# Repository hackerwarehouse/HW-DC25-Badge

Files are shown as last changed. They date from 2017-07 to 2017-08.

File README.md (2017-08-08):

# HW-DC25-Badge

This is the project page for the Hacker Warehouse electronic badge that was made for DEF CON 25.

## Background / timeline of badge development

* This was our first attempt at custom hardware / any electronics project at a larger scale
* 2 hardware revisions, 1 silkscreen revision = 3 prototype runs = 4-5 months
* After final board design was obtained, coding started (all code prior was test code to ensure components were working)
* 2 week code sprint before code needed to be frozen for mass badge flashing
* All boards flashed / all components obtained the week of travel of Las Vegas (one final box arrived the day prior to leaving which gave me some anxiety as well)
* 425 badges were produced 

## Badge Specs

* 96×64 Graphic Full Color OLED Display
* 14x Mini NeoPixel RGB LEDs
* ESP8266EX
* 4 tactile buttons arranged in Joypad configuration
* 8 MB Storage
* Powered via 2 AA batteries

## Badge Functions:

* 802.11 channel activity monitor
* Access point scanner
* LED patterns
* OLED animations
* Personalization
* Other useful network tools

## Release Notes
* There was debate if any/all the mischief tools should be included in the badge by default, include it but have them keycode unlockable, or just not include it in stock firmware. Because we know the people working on/in the Black Hat and DEF CON network, along with wanting to have a usable network without causing more issues, the features were not included. 
  * The continued usage of the word 'locked' in all areas made people assume it was all unlockable during the con. We should have chosen different words for the various areas of inclusion. Sorry about that. 

* Multiple reports during DEF CON on wifi functions not working after x usage. Originally suspected it was the sleep/wakeup or disconnect functions not being triggered properly but that doesn't seem to be it. 
  * As previously mentioned, all the badge software was in a two week sprint which didn't leave much or any time for debugging 

* We originally stated source/binaries would be released after the con but because of wifi bug we were wanting to debug and fix it prior to first public release. It seems like people want the code first so we are releasing it as is with the hopes more eyes on it the better and fixes can be submitted. 

## Compiling

These instructions will get you a copy of the project up and running on your local machine.

### Prerequisites

What things you need to install the software and how to install them

```
1. Arduino / compiler
2. Libraries via package manager
  https://github.com/esp8266/Arduino -> http://arduino.esp8266.com/versions/2.3.0/package_esp8266com_index.json
  https://github.com/adafruit/Adafruit_NeoPixel
  https://github.com/kitesurfer1404/WS2812FX
3. Manually copy the two other library packages to Arduino libraries folder
4. 3.3v serial cable
5. and of course a Hacker Warehouse DC25 Badge
```

### Uploading firmware to badge

1. Press / hold the up button on badge
2. Connect 3.3v serial cable
3. Use arduino compile to upload or use other methods such as esptool or esp8266_flasher (with binary file)
  * 115200

## Authors / Contributors

* **Garrett Gee**
* **Jaycon Systems**

## Acknowledgments

* Hat tip to anyone who's code was used
* All the supporters of this project
*

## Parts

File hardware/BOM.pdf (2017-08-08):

Part | Quantity | Manufacturer Part Number
0.1uF Capacitor | 14 | CL05B104KO5NNNC
10uF Capacitor | 2 | CL10A106MA8NRNC
0.1uF Capacitor | 3 | CL10B104KA8NNNC
10uF Capacitor | 2 | GRM188R61A106KE69D
10pF Capacitor | 2 | C1608C0G1H100C080AA
5.6pF Capacitor | 1 | CL10C5R6DB8NNNC
Schottky Diode | 1 | SS1P3L-M3/84A
RGB LED | 14 | 2659
Slide Switch | 1 | AYZ0202AGRLC
Push Button | 4 | TL3301NF100QG
Battery Holder | 1 | BC2AAPC
ESP8266 | 1 | ESP8266EX
LED Driver Regulator | 1 | FAN5331SX
8Mbit Flash | 1 | AT25SF081-SSHD-T
10uH Inductor | 1 | SRU5018-100Y
96x64 OLED | 1 | UG-9664HDDAG01
PCB | 1
100K Resistor | 1 | RC0603JR-07100KL
33K Resistor | 1 | RC0603FR-0733KL
10K Resistor | 5 | RC0603JR-0710KL
1M Resistor | 1 | RC0603FR-071ML
200 Resistor | 1 | RC0603FR-07200RL
16.5K Resistor | 1 | RC0603FR-0716K5L
12K Resistor | 1 | RC0603FR-0712KL
Stencil | 1
26MHz Crystal | 1 | TSX-3225 26.0000MF09Z-AC0

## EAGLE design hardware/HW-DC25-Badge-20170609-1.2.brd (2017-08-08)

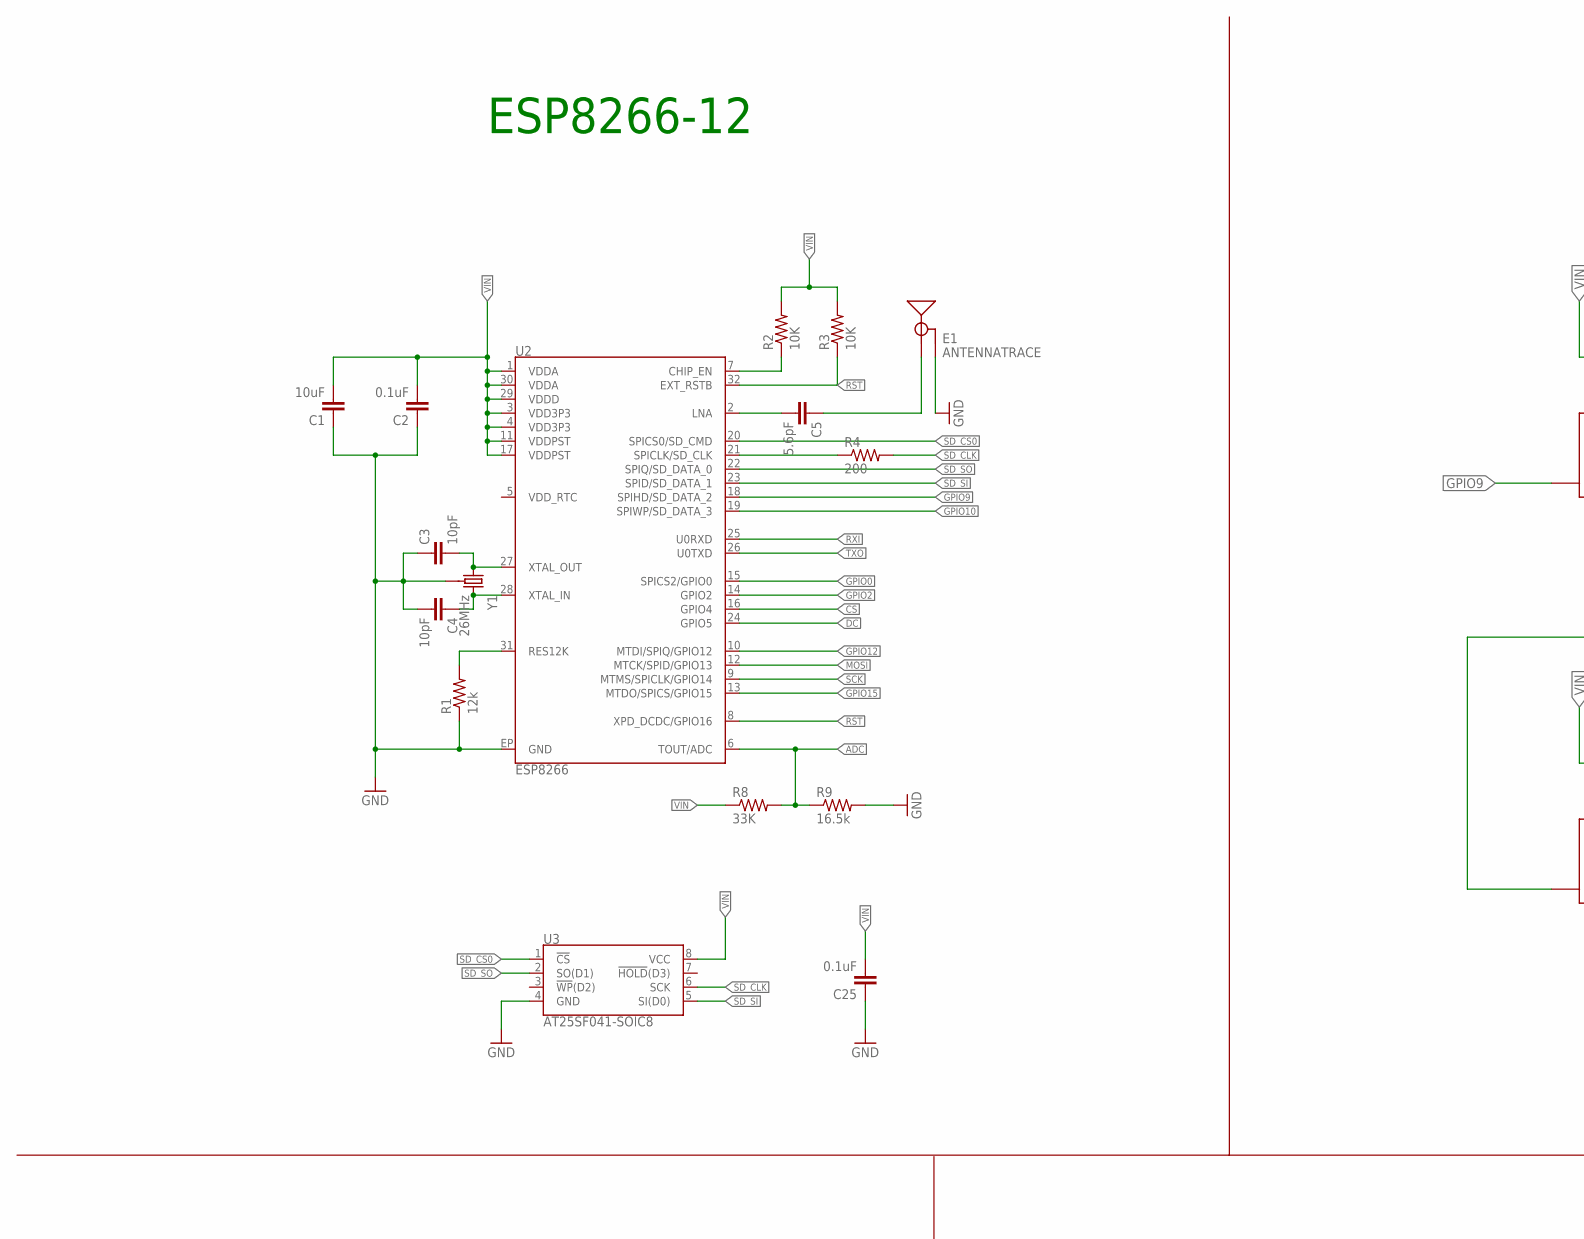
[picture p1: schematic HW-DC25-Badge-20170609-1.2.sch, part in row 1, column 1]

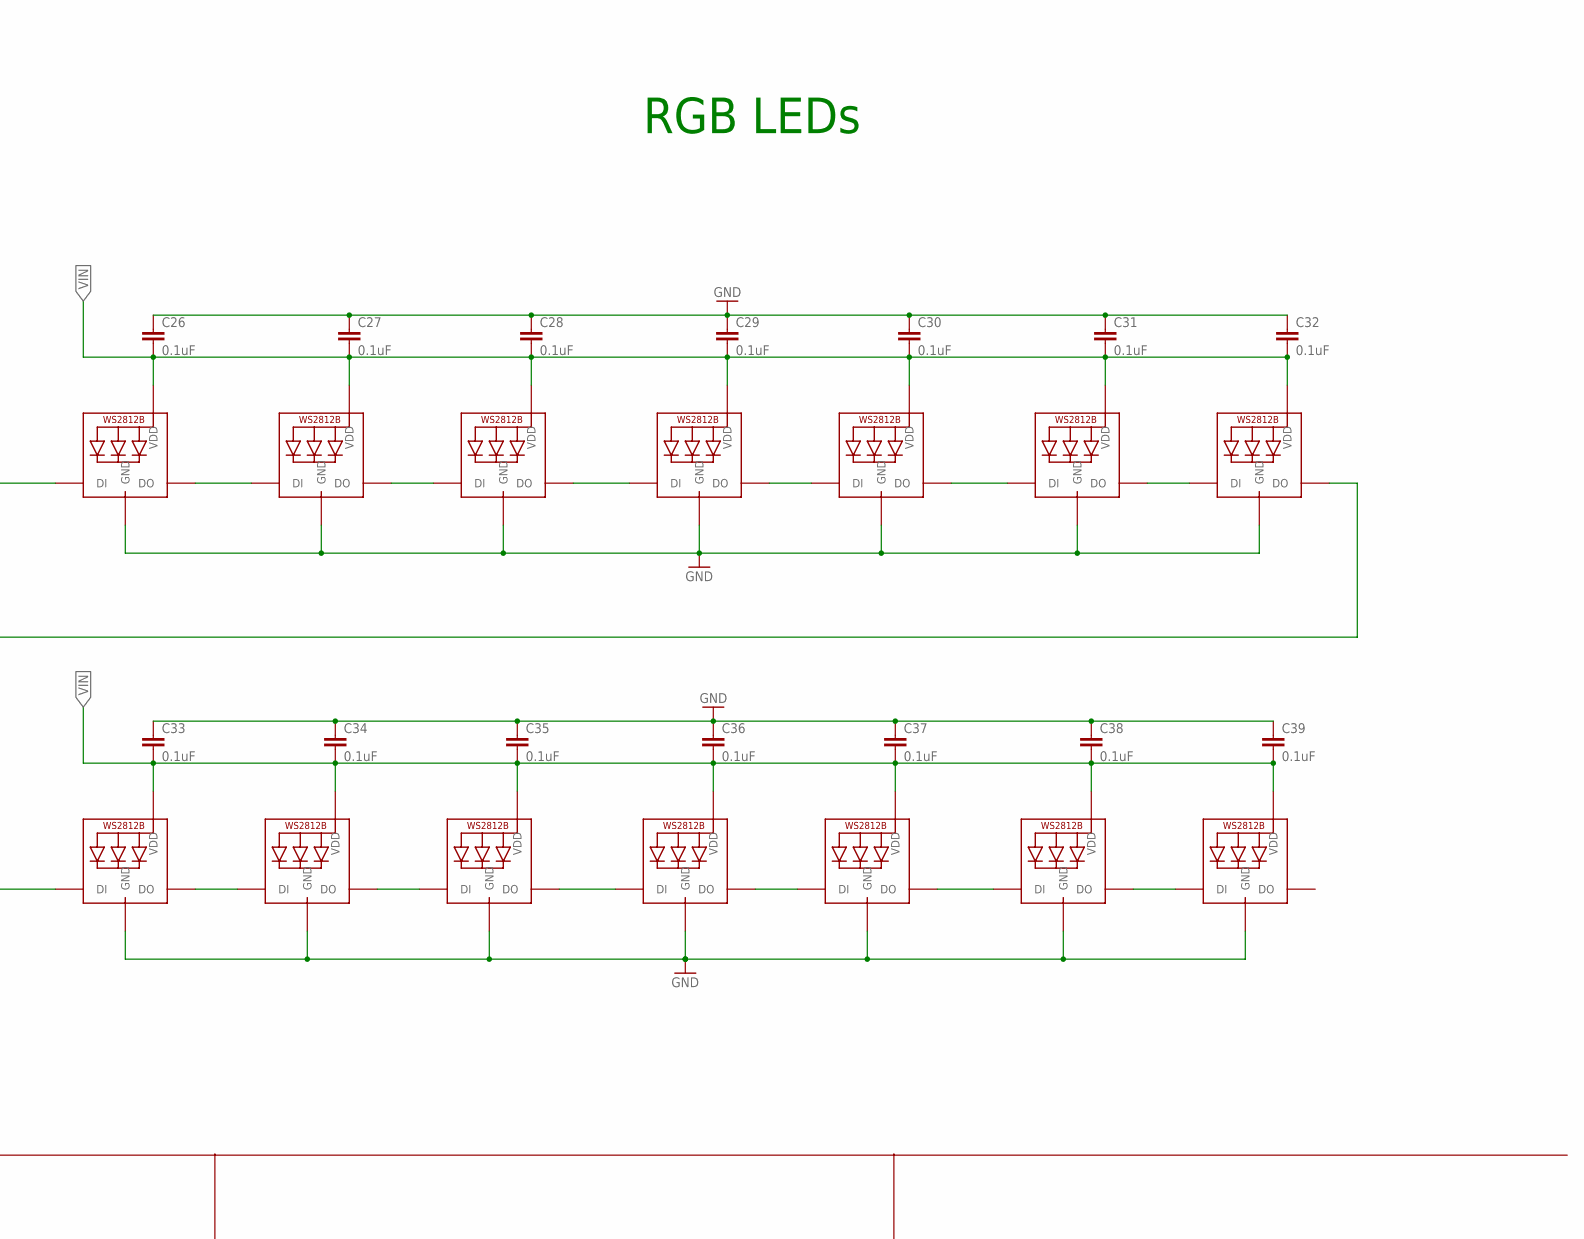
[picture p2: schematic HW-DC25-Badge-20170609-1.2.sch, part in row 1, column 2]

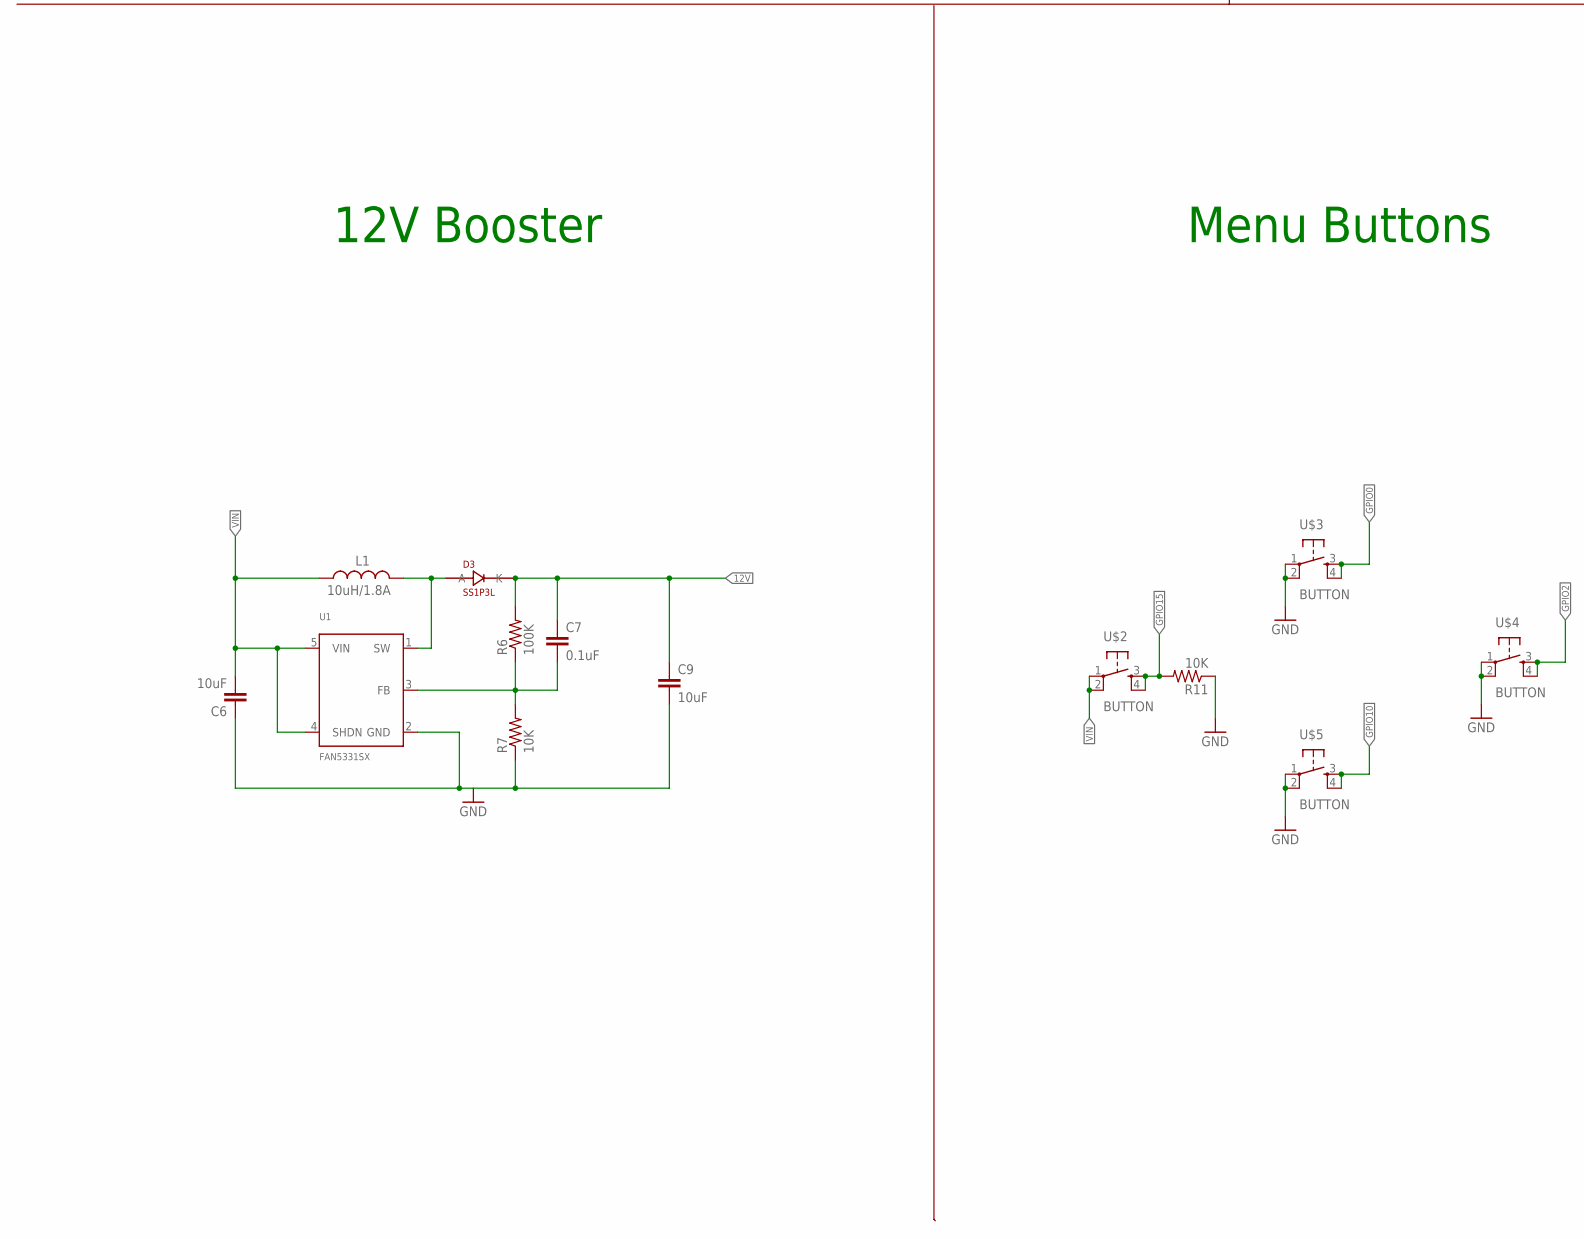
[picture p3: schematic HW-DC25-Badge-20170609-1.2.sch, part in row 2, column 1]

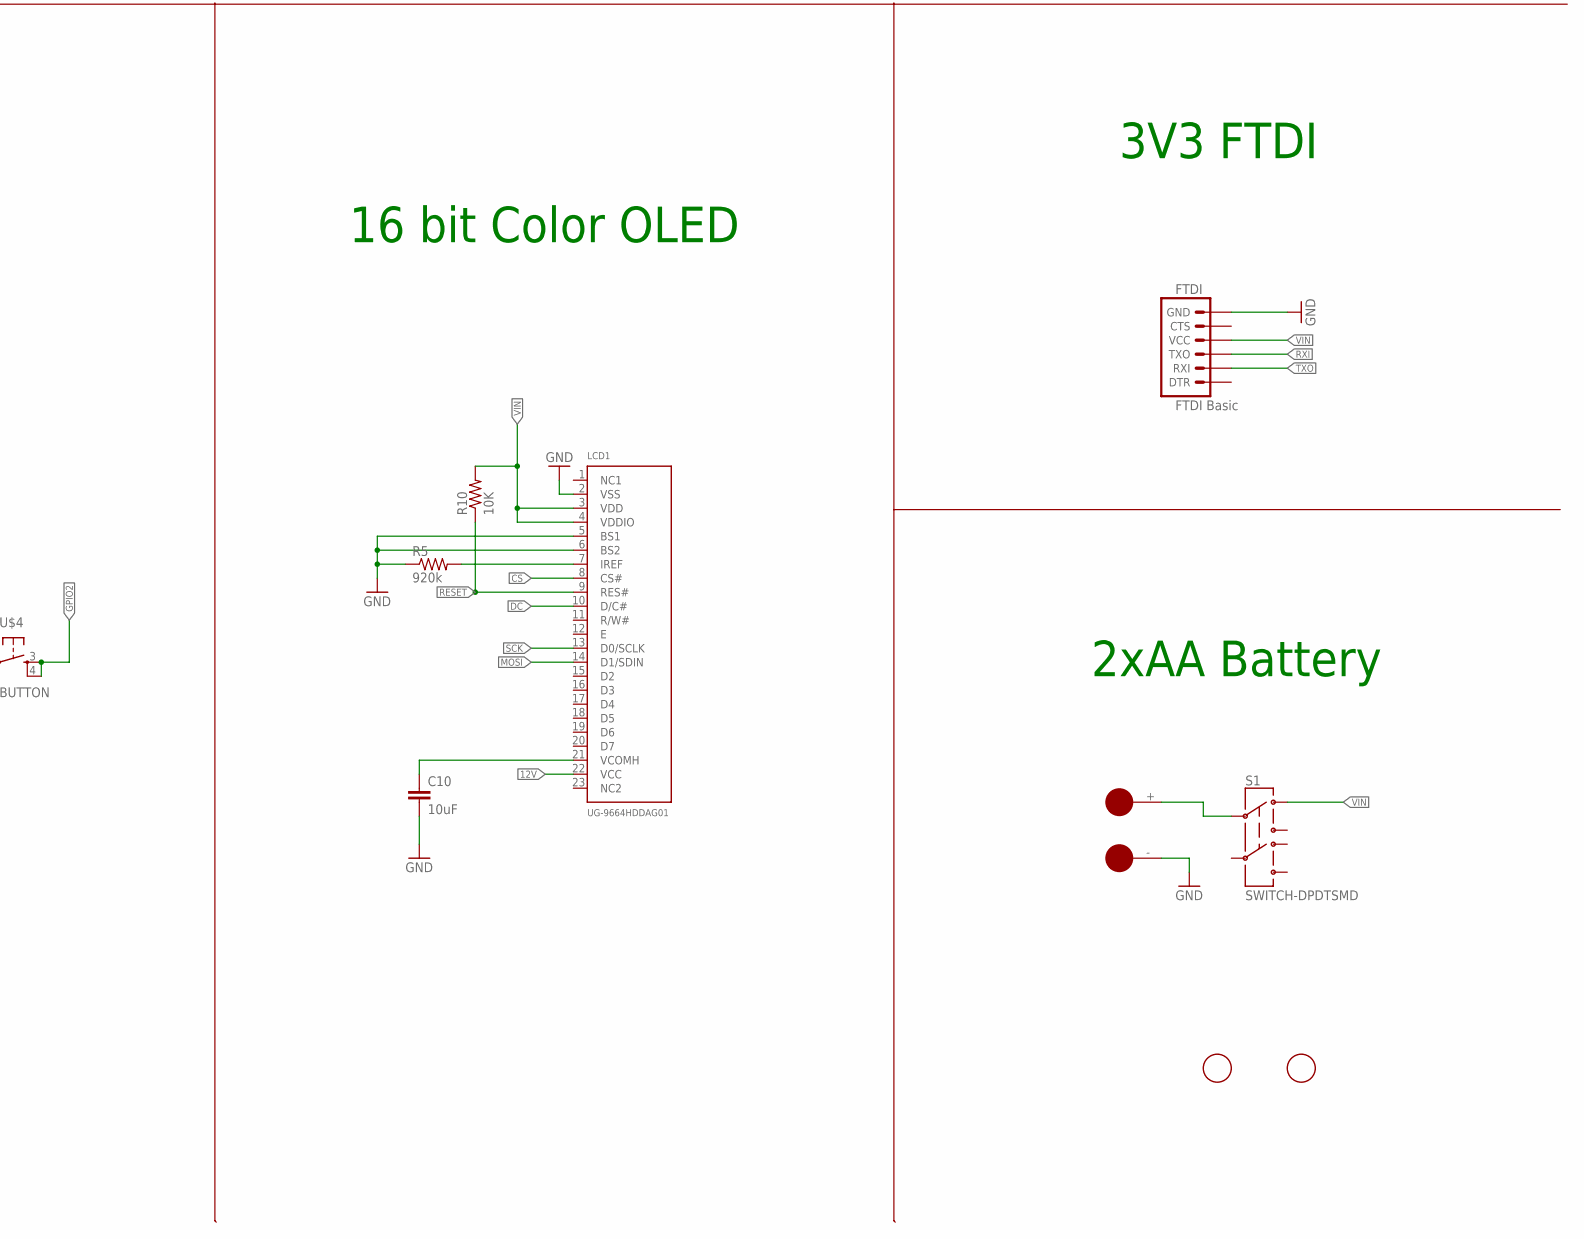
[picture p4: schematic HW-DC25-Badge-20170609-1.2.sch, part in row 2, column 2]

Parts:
C1, C6, C9, C10: 10uF; CAP0603
C2, C7, C25: 0.1uF; CAP0603
C3, C4: 10pF; CAP0603
C5: 5.6pF; CAP0603
C26, C27, C28, C29, C30, C31, C32, C33, C34, C35, C36, C37, C38, C39: 0.1uF; CAP0402
D3: SS1P3L; DO220AAL
E1: ANTENNATRACE; TRACE_ANTENNA_2.4GHZ_25.7MM
FTDI: FTDI Basic; 1X06
L1: 10uH/1.8A; SRU5028
LCD1: UG-9664HDDAG01; UG-9664HDDAG01_WRAPAROUND
LED1, LED2, LED3, LED4, LED5, LED6, LED7, LED8, LED9, LED10, LED11, LED12, LED13, LED14: WS2812B3535; LED3535
R1: 12k; RES-0603
R2, R3, R7, R10, R11: 10K; RES-0603
R4: 200; RES-0603
R5: 920k; RES-0603
R6: 100K; RES-0603
R8: 33K; RES-0603
R9: 16.5k; RES-0603
S1: SWITCH-DPDTSMD; AYZ0202
U1: FAN5331SX; SOT23-5
U2: ESP8266; QFN32
U3: AT25SF041-SOIC8; SO08
U$1: BAT_HOLD; AA
U$2, U$3, U$4, U$5: BUTTON
U$6, U$7: FIDUCIAL; FIDUCIAL_1MM
Y1: 26MHz; CRYSTAL-SMD-3.2X2.5

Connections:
12V: C7.1, C9.1, D3.P$1 (K), LCD1.22 (VCC), R6.2
ADC: R8.2, R9.1, U2.6 (TOUT/ADC)
CS: LCD1.8 (CS#), U2.16 (GPIO4)
DC: LCD1.10 (D/C#), U2.24 (GPIO5)
GND: C1.1, C2.1, C3.1, C4.2, C6.1, C9.2, C10.2, C25.1, C26.P$1 (1), C27.P$1 (1), C28.P$1 (1), C29.P$1 (1), C30.P$1 (1), C31.P$1 (1), C32.P$1 (1), C33.P$1 (1), C34.P$1 (1), C35.P$1 (1), C36.P$1 (1), C37.P$1 (1), C38.P$1 (1), C39.P$1 (1), E1.GND, E1.GND2 (GND), FTDI.6 (GND), LCD1.2 (VSS), LCD1.5 (BS1), LCD1.6 (BS2), LED1.4 (GND), LED2.4 (GND), LED3.4 (GND), LED4.4 (GND), LED5.4 (GND), LED6.4 (GND), LED7.4 (GND), LED8.4 (GND), LED9.4 (GND), LED10.4 (GND), LED11.4 (GND), LED12.4 (GND), LED13.4 (GND), LED14.4 (GND), R1.1, R5.1, R7.1, R9.2, R11.1, U1.2 (GND), U2.EP (GND), U3.4 (GND), U$1.-, U$3.1, U$3.2, U$4.1, U$4.2, U$5.1, U$5.2, Y1.2 (GND), Y1.4 (GND)
GPIO0: U2.15 (SPICS2/GPIO0), U$3.3, U$3.4
GPIO2: U2.14 (GPIO2), U$4.3, U$4.4
GPIO9: LED1.1 (DI), U2.18 (SPIHD/SD_DATA_2)
GPIO10: U2.19 (SPIWP/SD_DATA_3), U$5.3, U$5.4
GPIO12: U2.10 (MTDI/SPIQ/GPIO12)
GPIO15: R11.2, U2.13 (MTDO/SPICS/GPIO15), U$2.3, U$2.4
MOSI: LCD1.14 (D1/SDIN), U2.12 (MTCK/SPID/GPIO13)
unnamed: C3.2, U2.27 (XTAL_OUT), Y1.1
unnamed: C4.1, U2.28 (XTAL_IN), Y1.3 (2)
unnamed: C5.2, U2.2 (LNA)
unnamed: C5.1, E1.ANT (SIGNAL)
unnamed: R1.2, U2.31 (RES12K)
unnamed: R2.1, U2.7 (CHIP_EN)
unnamed: D3.P$2 (A), L1.2, U1.1 (SW)
unnamed: R4.1, U2.21 (SPICLK/SD_CLK)
unnamed: LCD1.7 (IREF), R5.2
unnamed: S1.2, U$1.+
unnamed: C7.2, R6.1, R7.2, U1.3 (FB)
unnamed: C10.1, LCD1.21 (VCOMH)
unnamed: LED1.3 (DO), LED2.1 (DI)
unnamed: LED2.3 (DO), LED3.1 (DI)
unnamed: LED3.3 (DO), LED4.1 (DI)
unnamed: LED4.3 (DO), LED5.1 (DI)
unnamed: LED5.3 (DO), LED6.1 (DI)
unnamed: LED6.3 (DO), LED7.1 (DI)
unnamed: LED7.3 (DO), LED8.1 (DI)
unnamed: LED8.3 (DO), LED9.1 (DI)
unnamed: LED9.3 (DO), LED10.1 (DI)
unnamed: LED10.3 (DO), LED11.1 (DI)
unnamed: LED11.3 (DO), LED12.1 (DI)
unnamed: LED12.3 (DO), LED13.1 (DI)
unnamed: LED13.3 (DO), LED14.1 (DI)
RESET: LCD1.9 (RES#), R10.1
RST: R3.1, U2.8 (XPD_DCDC/GPIO16), U2.32 (EXT_RSTB)
RXI: FTDI.3 (TXO), U2.25 (U0RXD)
SCK: LCD1.13 (D0/SCLK), U2.9 (MTMS/SPICLK/GPIO14)
SD_CLK: R4.2, U3.6 (SCK)
SD_CS0: U2.20 (SPICS0/SD_CMD), U3.1 (!CS!)
SD_SI: U2.23 (SPID/SD_DATA_1), U3.5 (SI(D0))
SD_SO: U2.22 (SPIQ/SD_DATA_0), U3.2 (SO(D1))
TXO: FTDI.2 (RXI), U2.26 (U0TXD)
VIN: C1.2, C2.2, C6.2, C25.2, C26.P$2 (2), C27.P$2 (2), C28.P$2 (2), C29.P$2 (2), C30.P$2 (2), C31.P$2 (2), C32.P$2 (2), C33.P$2 (2), C34.P$2 (2), C35.P$2 (2), C36.P$2 (2), C37.P$2 (2), C38.P$2 (2), C39.P$2 (2), FTDI.4 (VCC), L1.1, LCD1.3 (VDD), LCD1.4 (VDDIO), LED1.2 (VDD), LED2.2 (VDD), LED3.2 (VDD), LED4.2 (VDD), LED5.2 (VDD), LED6.2 (VDD), LED7.2 (VDD), LED8.2 (VDD), LED9.2 (VDD), LED10.2 (VDD), LED11.2 (VDD), LED12.2 (VDD), LED13.2 (VDD), LED14.2 (VDD), R2.2, R3.2, R8.1, R10.2, S1.1, U1.4 (SHDN), U1.5 (VIN), U2.1 (VDDA), U2.3 (VDD3P3), U2.4 (VDD3P3), U2.11 (VDDPST), U2.17 (VDDPST), U2.29 (VDDD), U2.30 (VDDA), U3.8 (VCC), U$2.1, U$2.2

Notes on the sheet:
ESP8266-12
RGB LEDs
12V Booster
Menu Buttons
16 bit Color OLED
3V3 FTDI
2xAA Battery

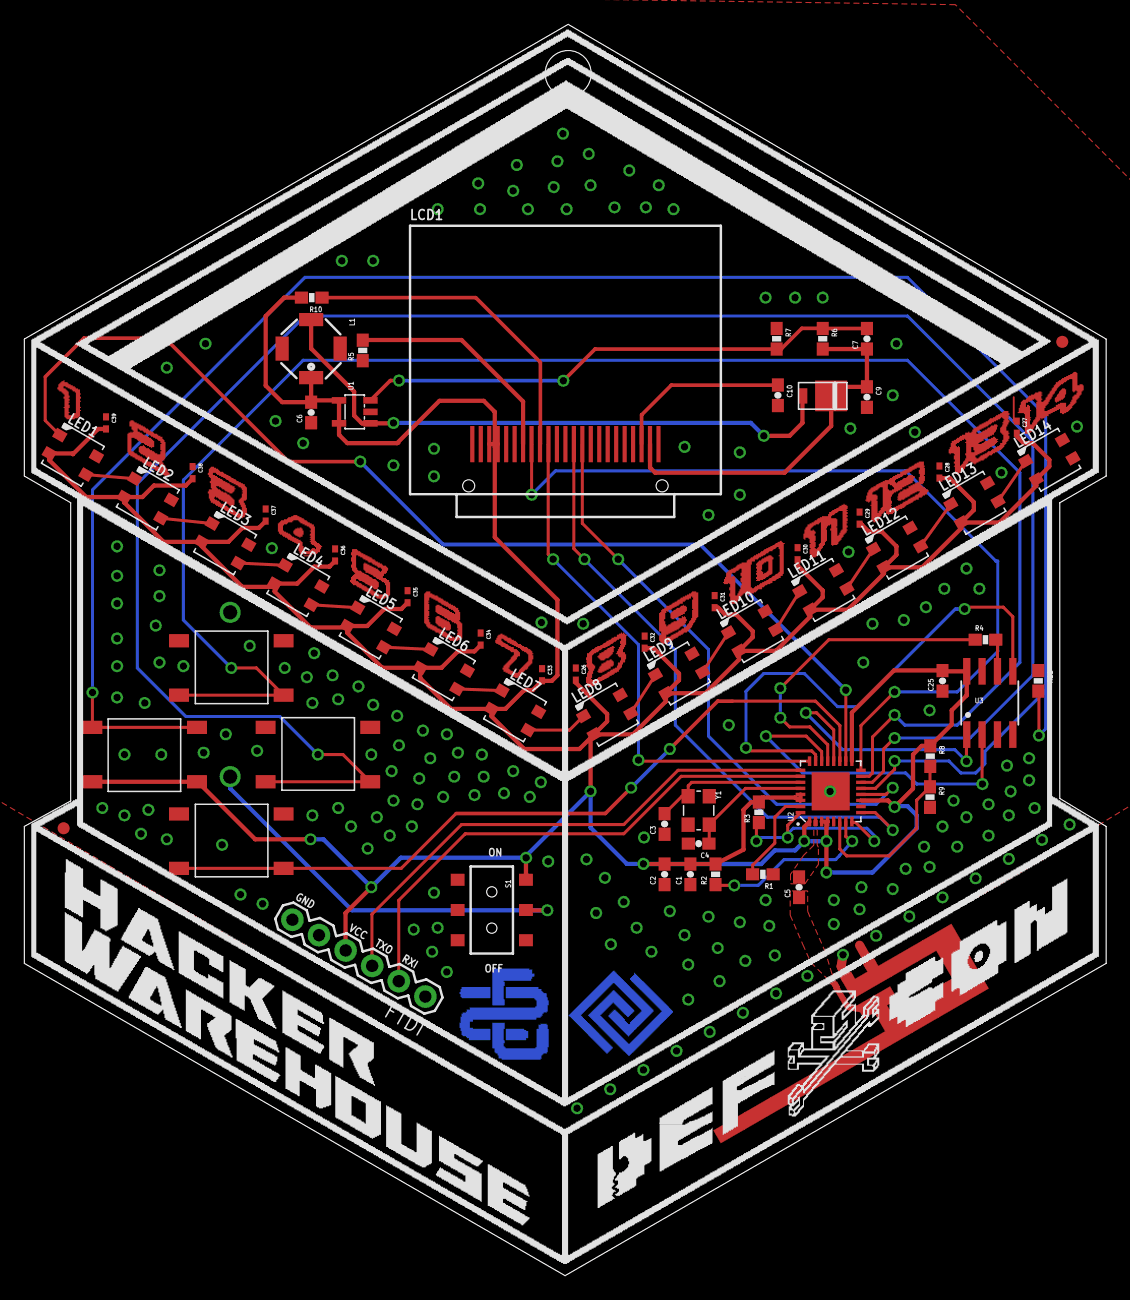
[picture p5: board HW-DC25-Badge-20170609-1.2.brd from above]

Board: 2 copper layers, 89.5 x 103.5 mm, 66 parts (1 on the bottom side), 46 nets.

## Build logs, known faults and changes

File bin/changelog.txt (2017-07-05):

HW-DC25-Badge-20170705.bin
 New
  - Snake game
  - Open AP finder
 Updates
 Tweaks
  - Client tools menu - saved for future additions

HW-DC25-Badge-20170701.bin
 Compile Info
  406306 bytes (38%) of program storage space
  Global variables use 48236 bytes (58%) of dynamic memory
 New
  - Text input via buttons
  - deauth monitor (single channel + nav)
  - deauth detector (all channel rotate)
  - client beacon sniffer
  - 3d cube demo
  - clock demo
 Updates
 Tweaks
  - Region settings
  - Menu organization

HW-DC25-Badge-20170629.bin
 New
  - Packet Monitor (single channel + nav)
  - Artwork Display
  - EEPROM settings
  - Button demo / unlocks
 Updates
  - AP Scanner
 Tweaks
  - Menus
  - Fixed logic in some routines

HW-DC25-Badge-20170624.bin
 New
  - Blinky modes

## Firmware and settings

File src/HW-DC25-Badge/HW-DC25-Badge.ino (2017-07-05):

#ifdef __AVR__
  #include <avr/power.h>
#endif
#include <EEPROM.h>
#include <SPI.h>

#include <Adafruit_NeoPixel.h>
#include <ESP8266WiFi.h>
#include <qMenuDisplay.h>
#include <qMenuSystem.h>
#include <SSD_13XX.h>
#include <WiFiClient.h>
#include <WiFiManager.h>
#include <WS2812FX.h>
#include "_fonts/defaultFont.c"

#include "about.h"
#include "apscanner.h"
#include "blinky.h"
#include "channelusage.h"
#include "core.h"
#include "extras.h"
#include "graphics.h"
#include "mainmenu.h"
#include "pkt1.h"
#include "pkt2.h"
#include "settings.h"

Adafruit_NeoPixel pixels = Adafruit_NeoPixel(NUMPIXELS, PIN, NEO_GRB + NEO_KHZ800);
WS2812FX ws2812fx = WS2812FX(NUMPIXELS, PIN, NEO_GRB + NEO_KHZ800);
SSD_13XX mydisp(_CS, _DC);
qMenuSystem menu=qMenuSystem(&mydisp);
WiFiManager wifiManager;

const byte left = 15; 
const byte down = 10; 
const byte right = 2; 
const byte up = 0;  

volatile byte btncounter = 0;
volatile byte btnid  = 0;
volatile byte region_id = 1;
volatile byte mydispbrightness;

byte appmode = 0;
byte region_unlocked = 0;

long debouncing_time = 250;
unsigned long last_micros = 0;

void UP(){
  if((long)(micros() - last_micros) >= debouncing_time * 1000) {
    if (appmode){      
    }
    else {
      btncounter ++;
    }
    btnid = 3;
    last_micros = micros();
  }
}

void DOWN(){
  if((long)(micros() - last_micros) >= debouncing_time * 1000) 
  {
    if (appmode){
    }
    else {
      btncounter ++;
    }
    btnid = 2;
    last_micros = micros();
  }
}

void RIGHT(){
  if((long)(micros() - last_micros) >= debouncing_time * 1000) {
    if (appmode){
    }
    else {
      btncounter ++;
    }
    btnid = 1;
    last_micros = micros();
  }
}

void LEFT(){
  if((long)(micros() - last_micros) >= debouncing_time * 1000) {
    if (appmode){
    }
    else {
      btncounter ++;
    }
    btnid = 4;
    last_micros = micros();
  }
}

void setup()
{  
  pinMode(up, INPUT_PULLUP);
  pinMode(down, INPUT_PULLUP);
  pinMode(right, INPUT_PULLUP);
  pinMode(left, INPUT);           //External pulldown resistor (required for programming)

  attachInterrupt(digitalPinToInterrupt(up), UP, FALLING);
  attachInterrupt(digitalPinToInterrupt(down), DOWN, FALLING);
  attachInterrupt(digitalPinToInterrupt(right), RIGHT, FALLING);
  attachInterrupt(digitalPinToInterrupt(left), LEFT, RISING);

  menu.InitMenu((const char **)mnuRoot,cntRoot,1);

  pixels.begin();
  ws2812fx.init();
  ws2812fx.setSpeed(200);

  loadSettings();
  all_leds_off();
  //wifi_off();
  
  Serial.begin(115200);
}

void menu_reset(){
  all_leds_off();
  mydisp.setFont(&defaultFont);
}

void all_leds_off(){
  for(int i=0;i<NUMPIXELS;i++){
    pixels.setPixelColor(i, pixels.Color(0,0,0));
    pixels.show();
  }  
}

void wifi_off(){
  WiFi.mode(WIFI_OFF);
  //WiFi.forceSleepBegin();
  delay(1);
}

void menu_force_escape(){
  btnid = 4;
  btncounter++;
}

void loop()
{ 
  int keycode=0;
  int clickedItem=0; 
  
  if (btncounter > 0)
  { 
    switch(btnid)
    {
      case 1:       
        clickedItem=menu.ProcessMenu(ACTION_SELECT);
        btncounter--;
        break;
      case 2:
        menu.ProcessMenu(ACTION_DOWN);
        btncounter--;
        break;      
      case 3:
        menu.ProcessMenu(ACTION_UP);
        btncounter--;
        break;
      case 4:
        clickedItem=menu.ProcessMenu(ACTION_BACK); 
        btncounter--;
        break;
    }
  }
  
  if (clickedItem > 0)
  {
    // Logic for root menu
    if (menu.CurrentMenu==mnuRoot)
      switch (clickedItem)
      {
        case 1:
          menu.InitMenu((const char ** )mnuWiFiTools,cntWiFiTools,1);
          mydisp.setBrightness(mydispbrightness);
          break;
        case 2:
          menu.InitMenu((const char ** )mnuBlinky,cntBlinky,1);
          mydisp.setBrightness(mydispbrightness);
          break;
        case 3:
          menu.InitMenu((const char ** )mnuGraphics,cntGraphics,1);
          mydisp.setBrightness(mydispbrightness);
          break;
//        case 4:
//          menu.InitMenu((const char ** )mnuClient,cntClient,1);
//          mydisp.setBrightness(mydispbrightness);
//          break; 
        case 4:
          menu.InitMenu((const char ** )mnuMischief,cntMischief,1);
          mydisp.setBrightness(mydispbrightness);
          break; 
        case 5:
          menu.InitMenu((const char ** )mnuExtra,cntExtra,1);
          mydisp.setBrightness(mydispbrightness);
          break;
        case 6:
          menu.InitMenu((const char ** )mnuSettings,cntSettings,1);
          mydisp.setBrightness(mydispbrightness);
          break;
        case 7:
          menu.InitMenu((const char ** )mnuAbout,cntAbout,1);
          mydisp.setBrightness(mydispbrightness);
          break;
      }

    // Logic for sub menus
    else if (menu.CurrentMenu==mnuWiFiTools)
      switch (clickedItem)
      {
        case 1:
          //WiFi.forceSleepWake();
          //delay(100);
          WiFi.mode(WIFI_STA);
          menu.MessageBox("Scanning...");
          AP_Channel_Usage();
          menu_reset();
          //wifi_off();
          break;
        case 2:
          //WiFi.forceSleepWake();
          //delay(100);
          menu.MessageBox("Scanning...");
          AP_Scanner();
          menu_reset();
          //wifi_off();
          break;
        case 3:
          //WiFi.forceSleepWake();
          //delay(100);
          Pkt_Monitor();
          menu_reset();
          //wifi_off();
          break;
        case 4:
          //WiFi.forceSleepWake();
          //delay(100);
          DeauthDetect();
          menu_reset();
          //wifi_off();
          break;
        case 5:
          //WiFi.forceSleepWake();
          //delay(100);
          DeauthMonitor();
          menu_reset();
          //wifi_off();
          break;
        case 6:
          //WiFi.forceSleepWake();
          //delay(100);
          menu.MessageBox("Locked");
          //FoxHunt();
          menu_reset();
          //wifi_off();
          break;
        case 7:
          //WiFi.forceSleepWake();
          //delay(100);
          Open_AP_Scanner();
          menu_reset();
          //wifi_off();
          break;
        case 8:
          //WiFi.forceSleepWake();
          //delay(100);
          ClientBeacons();
          menu_reset();
          //wifi_off();
          break;
      }

    else if (menu.CurrentMenu==mnuBlinky)
      switch (clickedItem)
      {
        case 1:
          mydisp.clearScreen();
          LED_WS2812FX_Favorites();
          menu_reset();
          break;
        case 2:
          mydisp.clearScreen();
          LED_Flashlight();
          menu_reset();
          break;
         case 3:
          mydisp.clearScreen();
          LED_WS2812FX_FullDemo();
          menu_reset();
          break;
         default:
          mydisp.clearScreen();
          byte ledmode = clickedItem - 3;
          LED_WS2812FX(ledmode);
          menu_reset();
          break; 
      }

    else if (menu.CurrentMenu==mnuGraphics)
      switch (clickedItem)
      {
        case 1:
          SelectArtwork();
          break;
        case 2:
          cubeDemo();
          break;
        case 3:
          clockDemo();
          break;
        case 4:
          gaugeDemo();
          break;
        case 5:
          GfxBenchmark();
          break;
      }

//    else if (menu.CurrentMenu==mnuClient)
//      switch (clickedItem)
//      {
//        case 1:
//          //connect
//          menu_reset();
//          break;
//        case 2:
//          break;
//        case 3:
//          break;
//        case 4:
//          menu.MessageBox("Disconnected");
//          WiFi.disconnect(); 
//          break;
//      }

    else if (menu.CurrentMenu==mnuMischief)
      switch (clickedItem)
      {
        case 1:
          //WiFi.forceSleepWake();
          //WiFi.mode(WIFI_AP_STA);
          menu.MessageBox("Locked");
          menu_reset();
          break;
        default:
          menu.MessageBox("Locked");
          menu_reset();
          break;
      }

    else if (menu.CurrentMenu==mnuExtra)
      switch (clickedItem)
      {
        case 1:
          menu.MessageBox("WiFi now off");
          wifi_off();
          break;
        case 2:
          snakeGame();
          break;
        case 3:
          ButtonEcho();
          break;
        case 4:
          KeyboardDemo();
          break;
      }

    else if (menu.CurrentMenu==mnuSettings)
      switch (clickedItem)
      {
        case 1:
          menu.InitMenu((const char ** )mnuBrightness,cntBrightness,1);
          mydisp.setBrightness(mydispbrightness);
          break;
        case 2:
          if (region_unlocked == 1) {
            menu.InitMenu((const char ** )mnuRegion,cntRegion,1);
            mydisp.setBrightness(mydispbrightness);
          }
          else { menu.MessageBox("Region is Locked"); }
          break;
        case 3:
          //configuration via webserver
          SettingsViaWiFi();
          break;
        case 4:
          break;
      }

    else if (menu.CurrentMenu==mnuBrightness)
      switch (clickedItem)
      {
        case 1:
          SaveBrightness(10,1);
          menu.MessageBox("Saved: Uber Low");
          delay(1000);
          menu_force_escape();
          break;
        case 2:
          SaveBrightness(64,4);
          menu.MessageBox("Saved: Low");
          delay(1000);
          menu_force_escape();
          break;
        case 3:
          SaveBrightness(128,7);
          menu.MessageBox("Saved: Medium");
          delay(1000);
          menu_force_escape();
          break;
        case 4:
          SaveBrightness(184,11);
          menu.MessageBox("Saved: High");
          delay(1000);
          menu_force_escape();
          break;
        case 5:
          SaveBrightness(254,15);
          menu.MessageBox("Be Careful");
          delay(1000);
          menu_force_escape();
          break;
      }
      
    else if (menu.CurrentMenu==mnuRegion)
      switch (clickedItem)
      {
       case 1:
          menu.MessageBox("Region Set: US");
          region_id = 1;  //US
          if (EEPROM.read(REGION_UNLOCK_ADDR)){
            EEPROM.write(REGION_ADDR,region_id);  
            EEPROM.commit();
          }
          break;
       case 2:
          menu.MessageBox("Region Set: EU");
          region_id = 2;
          if (EEPROM.read(REGION_UNLOCK_ADDR)){
            EEPROM.write(REGION_ADDR,region_id);  
            EEPROM.commit();
          }
          break;      
      }

    else if (menu.CurrentMenu==mnuAbout)
      switch (clickedItem)
      {
        case 1:
          SysInfo();
          break;
        case 2:
          IPConfig();
          break;
        case 3:
          Credits();
          break;
        case 4:
          Shouts();
          break;
        case 5:
          DebugInfo();
          break;
      } 
      
  }

  // menu return logic
  else if(clickedItem == -1){
    if (menu.CurrentMenu==mnuRoot)
      { //In root menu already - Do Nothing 
      }

    //2nd level menus
    else if (menu.CurrentMenu==mnuWiFiTools)   
      { menu.InitMenu((const char ** )mnuRoot,cntRoot,1); 
        mydisp.setBrightness(mydispbrightness);}
    else if (menu.CurrentMenu==mnuBlinky)
      { menu.InitMenu((const char ** )mnuRoot,cntRoot,2); 
        mydisp.setBrightness(mydispbrightness);}
    else if (menu.CurrentMenu==mnuGraphics)
      { menu.InitMenu((const char ** )mnuRoot,cntRoot,3); 
        mydisp.setBrightness(mydispbrightness);}
//    else if (menu.CurrentMenu==mnuClient)
//      { menu.InitMenu((const char ** )mnuRoot,cntRoot,4); 
//        mydisp.setBrightness(mydispbrightness);}
    else if (menu.CurrentMenu==mnuMischief)
      { menu.InitMenu((const char ** )mnuRoot,cntRoot,4); 
        mydisp.setBrightness(mydispbrightness);}
    else if (menu.CurrentMenu==mnuExtra)
      { menu.InitMenu((const char ** )mnuRoot,cntRoot,5); 
        mydisp.setBrightness(mydispbrightness);}
    else if (menu.CurrentMenu==mnuSettings)
      { menu.InitMenu((const char ** )mnuRoot,cntRoot,6); 
        mydisp.setBrightness(mydispbrightness);}
    else if (menu.CurrentMenu==mnuAbout)
      { menu.InitMenu((const char ** )mnuRoot,cntRoot,7); 
        mydisp.setBrightness(mydispbrightness);}

    //3rd level menus
    else if (menu.CurrentMenu==mnuBrightness)
      { menu.InitMenu((const char ** )mnuSettings,cntSettings,1); 
        mydisp.setBrightness(mydispbrightness);}
    else if (menu.CurrentMenu==mnuRegion)
      { menu.InitMenu((const char ** )mnuSettings,cntSettings,3); 
        mydisp.setBrightness(mydispbrightness);}
   }
 }

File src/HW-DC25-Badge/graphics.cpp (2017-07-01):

#include <EEPROM.h>
#include <SPI.h>

#include <SSD_13XX.h>

#include "core.h"

extern SSD_13XX mydisp;
extern byte appmode;
extern byte btncounter;
extern volatile byte btnid;

////////////////////////////////////////////////////////////////////////////////////////////////////////////////////

#include "_images/badge.c"
#include "_images/godai_1.c"
#include "_images/defcon.c"
#include "_images/hackerwarehouse.c"

void DisplayArtwork(byte img){
  int h, w, buffidx;
  int row, col;
  switch(img)
  {
   case 1:
      h = 31;
      w = 95;
      buffidx = 0;
      mydisp.clearScreen(); 
      for (row=0; row<h; row++) {
        for (col=0; col<w; col++) { 
          mydisp.drawPixel(col, row+20, pgm_read_word(image_data_hackerwarehouse + buffidx));
          buffidx++;
        } 
      }
      break;
   case 2:
      h = 25;
      w = 96;
      buffidx = 0;
      mydisp.clearScreen(); 
      for (row=0; row<h; row++) {
        for (col=0; col<w; col++) { 
          mydisp.drawPixel(col, row+20, pgm_read_word(image_data_defcon + buffidx));
          buffidx++;
        } 
      }
      break;
   case 3:
      h = 63;
      w = 73;
      buffidx = 0;
      mydisp.clearScreen();
      for (row=0; row<h; row++) {
        for (col=0; col<w; col++) { 
          mydisp.drawPixel(col+11, row, pgm_read_word(image_data_badge + buffidx));
          buffidx++;
        } 
      }
      break;
   case 4:
      h = 63;
      w = 63;
      buffidx = 0;
      mydisp.clearScreen();
      for (row=0; row<h; row++) {
        for (col=0; col<w; col++) { 
          mydisp.drawPixel(col+17, row, pgm_read_word(image_data_godai_1 + buffidx));
          buffidx++;
        } 
      }
      break;
  }
}

void SelectArtwork(){
  appmode=1;
  byte count=1;
  byte last=0;
  btnid = 0;
  while (1)
  {
    if (btnid == 3){ 
      if (count == 4) {count = 1; } 
      else {count++;}
      btnid = 0;
    }
    else if (btnid == 2){ 
      if (count == 1) {count = 4; } 
      else {count--;}
      btnid = 0;
    }
    else if (btnid == 1){
      EEPROM.write(ARTWORK_ADDR,count);
      EEPROM.commit();
      mydisp.clearScreen();
      mydisp.setCursor(0, 0);
      mydisp.setTextColor(GREENYELLOW);
      mydisp.setTextScale(3);
      mydisp.println(F("Saved"));
      delay(1000);
      btnid = 4;
      break;
    }
    else if (btnid == 4) {break;}

    if (count != last)
    {
      last=count;
      DisplayArtwork(last); 
    }
    delay(100);
  }
  appmode=0;
  btncounter++;
}

////////////////////////////////////////////////////////////////////////////////////////////////////////////////////

unsigned long testFillScreen() {
  unsigned long start = micros();
  mydisp.clearScreen();
  mydisp.fillScreen(RED);
  mydisp.fillScreen(GREEN);
  mydisp.fillScreen(BLUE);
  mydisp.clearScreen();
  return micros() - start;
}

unsigned long testText() {
  mydisp.clearScreen();
  unsigned long start = micros();
  mydisp.setCursor(0, 0);
  mydisp.setTextColor(WHITE);
  mydisp.setTextScale(1);
  mydisp.println("Hello World!");
  mydisp.setTextColor(YELLOW);
  mydisp.setTextScale(2);
  mydisp.println(1234.56);
  mydisp.setTextColor(RED);
  mydisp.setTextScale(3);
  mydisp.println(0xDEAD, HEX);
  mydisp.println();
  mydisp.setTextColor(GREEN);
  mydisp.setTextScale(4);
  mydisp.println("Hello");
  return micros() - start;


}

unsigned long testText2() {
  mydisp.clearScreen();
  unsigned long start = micros();
  mydisp.setCursor(0, 0);
  mydisp.setTextColor(WHITE);
  mydisp.setTextScale(2);
  mydisp.println(F("I implore thee,"));
  mydisp.setTextScale(1);
  mydisp.println(F("my foonting turlingdromes."));
  mydisp.println(F("And hooptiously drangle me"));
  mydisp.println(F("with crinkly bindlewurdles,"));
  mydisp.println(F("Or I will rend thee"));
  mydisp.println(F("in the gobberwarts"));
  mydisp.println(F("with my blurglecruncheon,"));
  mydisp.println(F("see if I don't!"));
  return micros() - start;
}

unsigned long testLines(uint16_t color) {
  unsigned long start, t;
  int           x1, y1, x2, y2,
                w = mydisp.width(),
                h = mydisp.height();

  mydisp.clearScreen();

  x1 = y1 = 0;
  y2    = h - 1;
  start = micros();
  for (x2 = 0; x2 < w; x2 += 6) mydisp.drawLine(x1, y1, x2, y2, color);
  x2    = w - 1;
  for (y2 = 0; y2 < h; y2 += 6) mydisp.drawLine(x1, y1, x2, y2, color);
  t     = micros() - start; // fillScreen doesn't count against timing

  mydisp.clearScreen();

  x1    = w - 1;
  y1    = 0;
  y2    = h - 1;
  start = micros();
  for (x2 = 0; x2 < w; x2 += 6) mydisp.drawLine(x1, y1, x2, y2, color);
  x2    = 0;
  for (y2 = 0; y2 < h; y2 += 6) mydisp.drawLine(x1, y1, x2, y2, color);
  t    += micros() - start;

  mydisp.clearScreen();

  x1    = 0;
  y1    = h - 1;
  y2    = 0;
  start = micros();
  for (x2 = 0; x2 < w; x2 += 6) mydisp.drawLine(x1, y1, x2, y2, color);
  x2    = w - 1;
  for (y2 = 0; y2 < h; y2 += 6) mydisp.drawLine(x1, y1, x2, y2, color);
  t    += micros() - start;

  mydisp.clearScreen();

  x1    = w - 1;
  y1    = h - 1;
  y2    = 0;
  start = micros();
  for (x2 = 0; x2 < w; x2 += 6) mydisp.drawLine(x1, y1, x2, y2, color);
  x2    = 0;
  for (y2 = 0; y2 < h; y2 += 6) mydisp.drawLine(x1, y1, x2, y2, color);

  return micros() - start;
}

unsigned long testFastLines(uint16_t color1, uint16_t color2) {
  unsigned long start;
  int           x, y, w = mydisp.width(), h = mydisp.height();

  mydisp.clearScreen();
  start = micros();
  for (y = 0; y < h; y += 5) mydisp.drawFastHLine(0, y, w, color1);
  for (x = 0; x < w; x += 5) mydisp.drawFastVLine(x, 0, h, color2);

  return micros() - start;
}

unsigned long testRects(uint16_t color) {
  unsigned long start;
  int           n, i, i2,
                cx = mydisp.width()  / 2,
                cy = mydisp.height() / 2;

  mydisp.clearScreen();
  n     = min(mydisp.width(), mydisp.height());
  start = micros();
  for (i = 2; i < n; i += 6) {
    i2 = i / 2;
    mydisp.drawRect(cx - i2, cy - i2, i, i, color);
  }

  return micros() - start;
}

unsigned long testFilledRects(uint16_t color1, uint16_t color2) {
  unsigned long start, t = 0;
  int           n, i, i2,
                cx = (mydisp.width()  / 2) - 1,
                cy = (mydisp.height() / 2) - 1;

  mydisp.clearScreen();
  n = min(mydisp.width(), mydisp.height());
  for (i = n; i > 0; i -= 6) {
    i2    = i / 2;
    start = micros();
    mydisp.fillRect(cx - i2, cy - i2, i, i, color1);
    t    += micros() - start;
    // Outlines are not included in timing results
    mydisp.drawRect(cx - i2, cy - i2, i, i, color2);
  }

  return t;
}

unsigned long testFilledCircles(uint8_t radius, uint16_t color) {
  unsigned long start;
  int x, y, w = mydisp.width(), h = mydisp.height(), r2 = radius * 2;

  mydisp.clearScreen();
  start = micros();
  for (x = radius; x < w; x += r2) {
    for (y = radius; y < h; y += r2) {
      mydisp.fillCircle(x, y, radius, color);
    }
  }

  return micros() - start;
}
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

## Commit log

2017-06-06 moved led functions to own file
2017-06-18 menu code cleanup
    - major cleanup of code that drives menu
    - fixed blinky modes to utilize loops
    [HW-DC25-Badge.ino]
2017-06-18 minor fixes
    - fixed commenting error
    - changed strings back to PROGMEM
    [HW-DC25-Badge.ino]
2017-06-19 led mode updates
    - using WS2812FX library
    - 49 blinky modes total currently
    - kept our original sample code for reference
    - renamed counter to btncounter
2017-06-19 about info updates
    - hwinfo added
    - changed structure of print of text
2017-06-22 optimizations
    - blinky favorites order improved
    - changed order of blinky menu
    - added appmode button menu bypass
    - adopted shouts function to new appmode function. much improved
    - artwork images
2017-06-24 artwork
    - persistent setting of saved artwork
    - 3 options currently
    - renamed small artwork used in credits
2017-06-25 button echo
    - function works itself
    - doesn't trigger anything so it is more for future references
    [HW-DC25-Badge.ino, core.h]
2017-06-26 channel activity / channel usage
    - renamed JS channel activity to channel usage as it is a better title match
    - created channel activity packet monitor tool via monitor mode
    - minor bugs in new channel activity app but main parts work
    - commented out all the forceSleepBeing and forceSleepWake calls. too many issues with this right now
    [HW-DC25-Badge.ino]
2017-06-29 organization / cleanup
    - moved shouts to about
    - moved benchmark to graphics
    - moved artwork to graphics
    - moved button echo to extras
    - added keyboard demo to extras
    - re-organized menu
2017-07-01 deauth code
    - renamed pktmonitor to packetpower
    - which includes packet monitor and deauth monitor and detector functions currently
    - fixed menu order
    [HW-DC25-Badge.ino]
2017-07-03 bug fix / code cleanup
    - fixed channel 1 display bug
    - removed led flasher code - was distracting
2017-08-08 hardware source files sync
    [HW-DC25-Badge-20170609-1.2.brd, HW-DC25-Badge-20170609-1.2.sch]

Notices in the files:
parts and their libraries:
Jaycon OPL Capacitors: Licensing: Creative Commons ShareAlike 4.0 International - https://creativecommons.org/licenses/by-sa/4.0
